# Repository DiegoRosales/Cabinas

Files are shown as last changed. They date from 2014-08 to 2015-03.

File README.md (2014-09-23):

Proyecto Cabinas
=======
---

**Última revisión del PCB del control:** 09/09/2014.

**Última revisión del PCB de la botonera:** 29/07/2014.

**Última revisión del código del control:** 23/09/2014.

**Última revisión del código de la botonera:** 1/09/2014

# Esquemático del PCB de control

# Esquemático de la botonera

# Tabla de cableado

# BOM
[Bill of materials](https://github.com/DiegoRosales/Cabinas/blob/master/PCB/Cabinas/BOM/BOM.xlsx)

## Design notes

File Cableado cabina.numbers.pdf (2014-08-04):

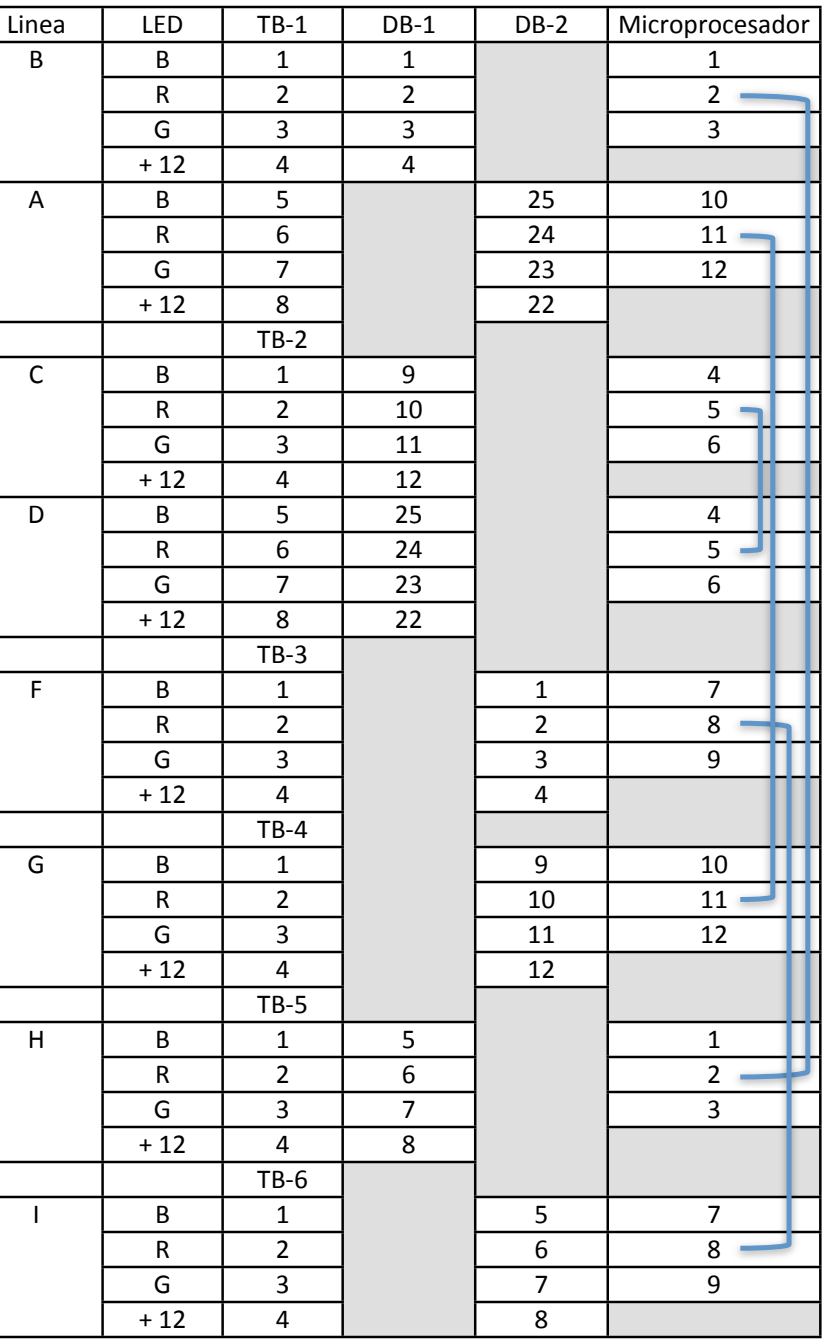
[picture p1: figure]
Linea; LED; Microprocesador

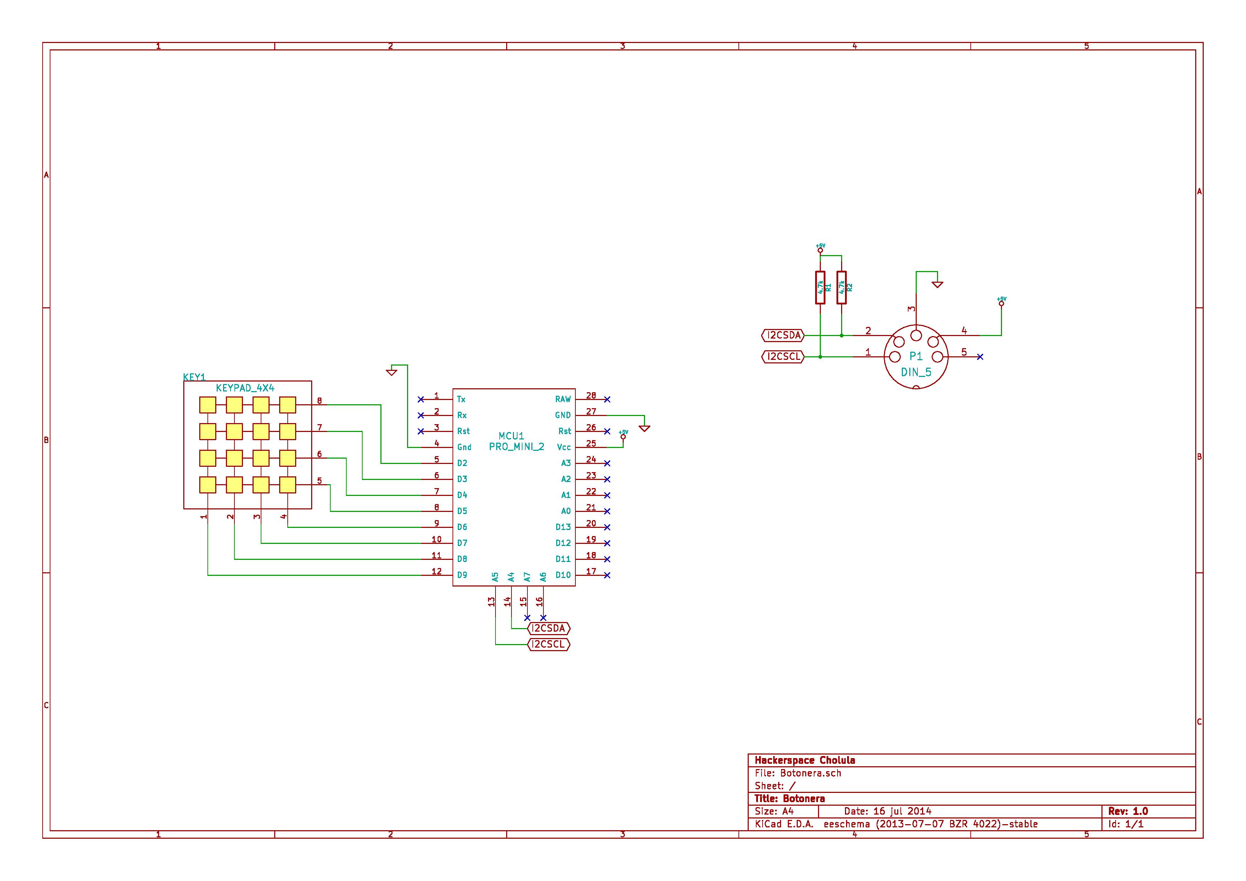
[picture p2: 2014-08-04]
PCB/Botonera/Schematic.jpg

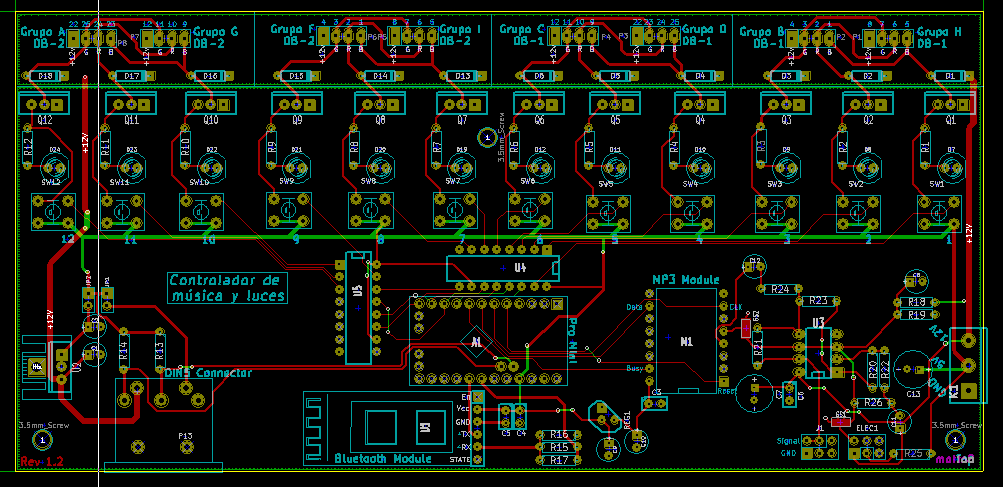
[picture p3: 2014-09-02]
Captura.PNG

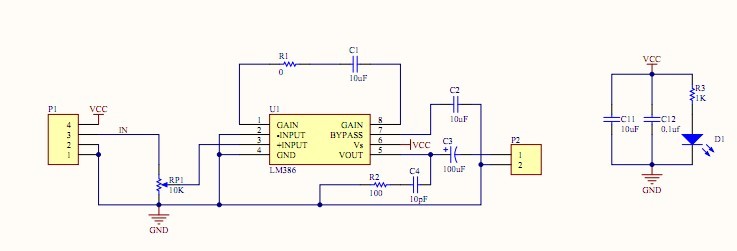
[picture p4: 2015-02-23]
PCB/Cabinas/Esquematico/lm386 mini circuit.jpg

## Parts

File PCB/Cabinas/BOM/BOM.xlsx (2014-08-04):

Reference | Value | Type
A1 | - | Arduino Pro Mini 5V
C1 | 0.33uF | Ceramic Capacitor
C9, C10, C11, C12 | 1uF | Electrolytic Capacitor
C7, C13 | 470uF | Electrolytic Capacitor
C2, C3, C4, C5, C6 | 0.1uF | Ceramic Capacitor
C8 | 47uF | Electrolytic Capacitor
D7, D8, D9, D10, D11, D12, D19, D20, D21, D22, D23, D24 | LED | LED
D1, D2, D3, D4, D5, D6D13, D14, D15, D16, D17, D18 | 1N4001 | Diode
ELEC1 | - | Electret Microphone
GS1 | - | Solder jumper
GS2 | - | Solder jumper
J1 | JACK_ST_3SW | Jack
JP1, JP2 | - | Pin header 2x
K1 | - | Pin header 3x
M1 | WTV020-SD | MP3 Module
P1, P2, P3, P4, P5, P6, P7, P8 | - | LED Strip output
P13 | - | DIN 5 Connector
Q1, Q2, Q3, Q4, Q5, Q6, Q7, Q8, Q9, Q10, Q11, Q12 |  | Mosfet transistor
R1, R2, R3, R4, R5, R6, R7, R8, R9, R10, R11, R12, R15, R16, R17 | 1k | Resistor
R13, R14 | 4.7k | Resistor
R18, R19, R21, R22, R23, R24, R26 | 10k | Resistor
R20 | 270k | Resistor
R25 | 2.2k | Resistor
REG1 | NPC1700 | 3.3V Regulator
SW1, SW2, SW3, SW4, SW5, SW6, SW7, SW8, SW9, SW10, SW11, SW12 | - | Tactile Switch
U1 | - | Bluetooth module
U2 | 7805 | 5V Regulator
U3 | TL072 | Operational Amplifier
U4, U5 | 74HC595 | Shift Register

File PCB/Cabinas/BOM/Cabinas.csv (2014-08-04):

ref | value
A1 | PROMINI
C1 | 0.33uF
C2 | 0.1uF
C3 | 0.1uF
C4 | 0.1uF
C5 | 0.1uF
C6 | 0.1uF
C7 | 470uF
C8 | 47uF
C9 | 1uF
C10 | 1uF
C11 | 1uF
C12 | 1uF
C13 | 470uF
D1 | DIODE
D2 | DIODE
D3 | DIODE
D4 | DIODE
D5 | DIODE
D6 | DIODE
D7 | LED
D8 | LED
D9 | LED
D10 | LED
D11 | LED
D12 | LED
D13 | DIODE
D14 | DIODE
D15 | DIODE
D16 | DIODE
D17 | DIODE
D18 | DIODE
D19 | LED
D20 | LED
D21 | LED
D22 | LED
D23 | LED
D24 | LED
ELEC1 | ELECTRET_MIC_SUP
GS1 | GS3
GS2 | GS3
J1 | JACK_ST_3SW
JP1 | JUMPER
JP2 | JUMPER
K1 | CONN_3
M1 | WTV020-SD
P1 | CONN_4
P2 | CONN_4
P3 | CONN_4
P4 | CONN_4
P5 | CONN_4
P6 | CONN_4
P7 | CONN_4
P8 | CONN_4
P13 | DIN_5
Q1 | MOSFET_N
Q2 | MOSFET_N
Q3 | MOSFET_N
Q4 | MOSFET_N
Q5 | MOSFET_N
Q6 | MOSFET_N
Q7 | MOSFET_N
Q8 | MOSFET_N
Q9 | MOSFET_N
Q10 | MOSFET_N
Q11 | MOSFET_N
Q12 | MOSFET_N
R1 | 1k
R2 | 1k
R3 | 1k
R4 | 1k
R5 | 1k
R6 | 1k
R7 | 1k
R8 | 1k
R9 | 1k
R10 | 1k
R11 | 1k
R12 | 1k
R13 | 4.7k
R14 | 4.7k
R15 | 1k
R16 | 1k
R17 | 1k
R18 | 10k
R19 | 10k
R20 | 270k
R21 | 10k
R22 | 10k
R23 | 10k
R24 | 10k
R25 | 2.2k
R26 | 10k
REG1 | NPC1700
SW1 | PUSHBUTTON
SW2 | PUSHBUTTON
SW3 | PUSHBUTTON
SW4 | PUSHBUTTON
SW5 | PUSHBUTTON
SW6 | PUSHBUTTON
SW7 | PUSHBUTTON
SW8 | PUSHBUTTON
SW9 | PUSHBUTTON
SW10 | PUSHBUTTON
SW11 | PUSHBUTTON
SW12 | PUSHBUTTON
U1 | BTM_2
U2 | 7805
U3 | TL072
U4 | 74HC595
U5 | 74HC595

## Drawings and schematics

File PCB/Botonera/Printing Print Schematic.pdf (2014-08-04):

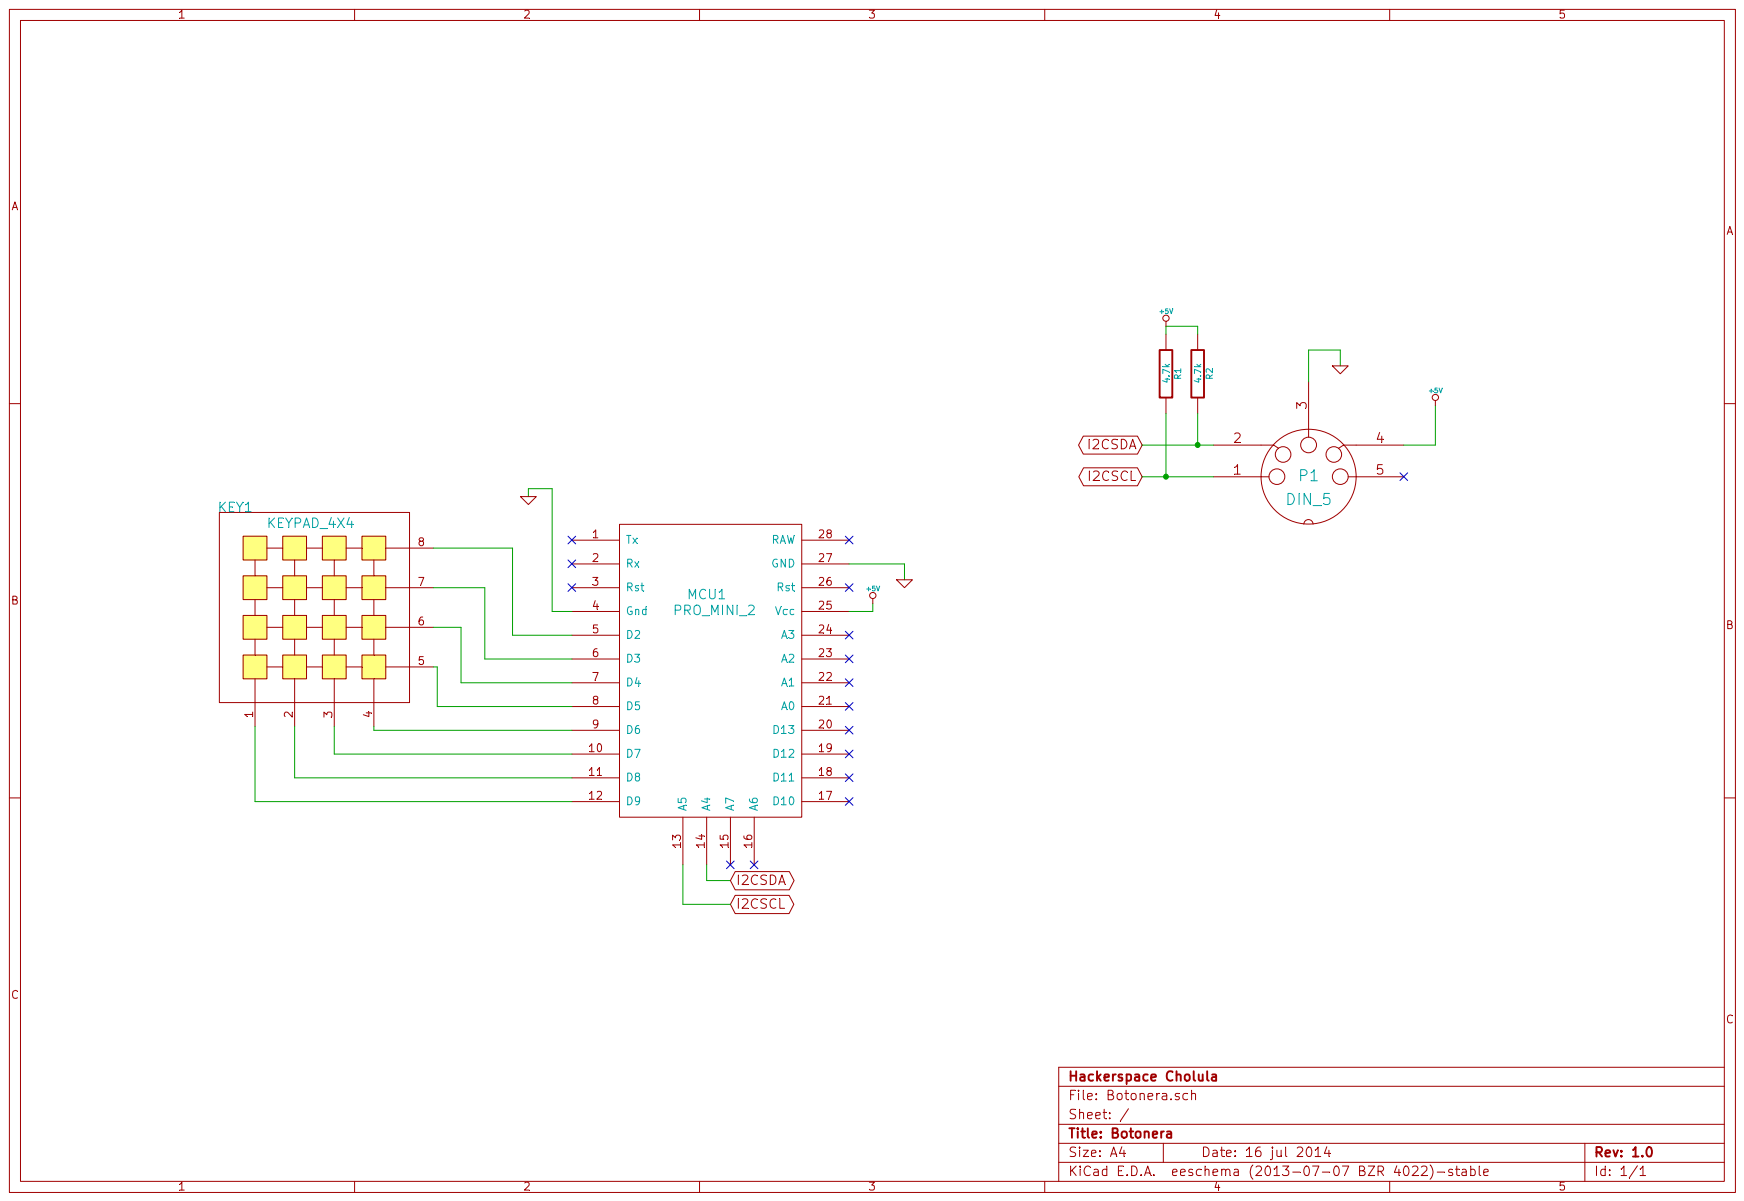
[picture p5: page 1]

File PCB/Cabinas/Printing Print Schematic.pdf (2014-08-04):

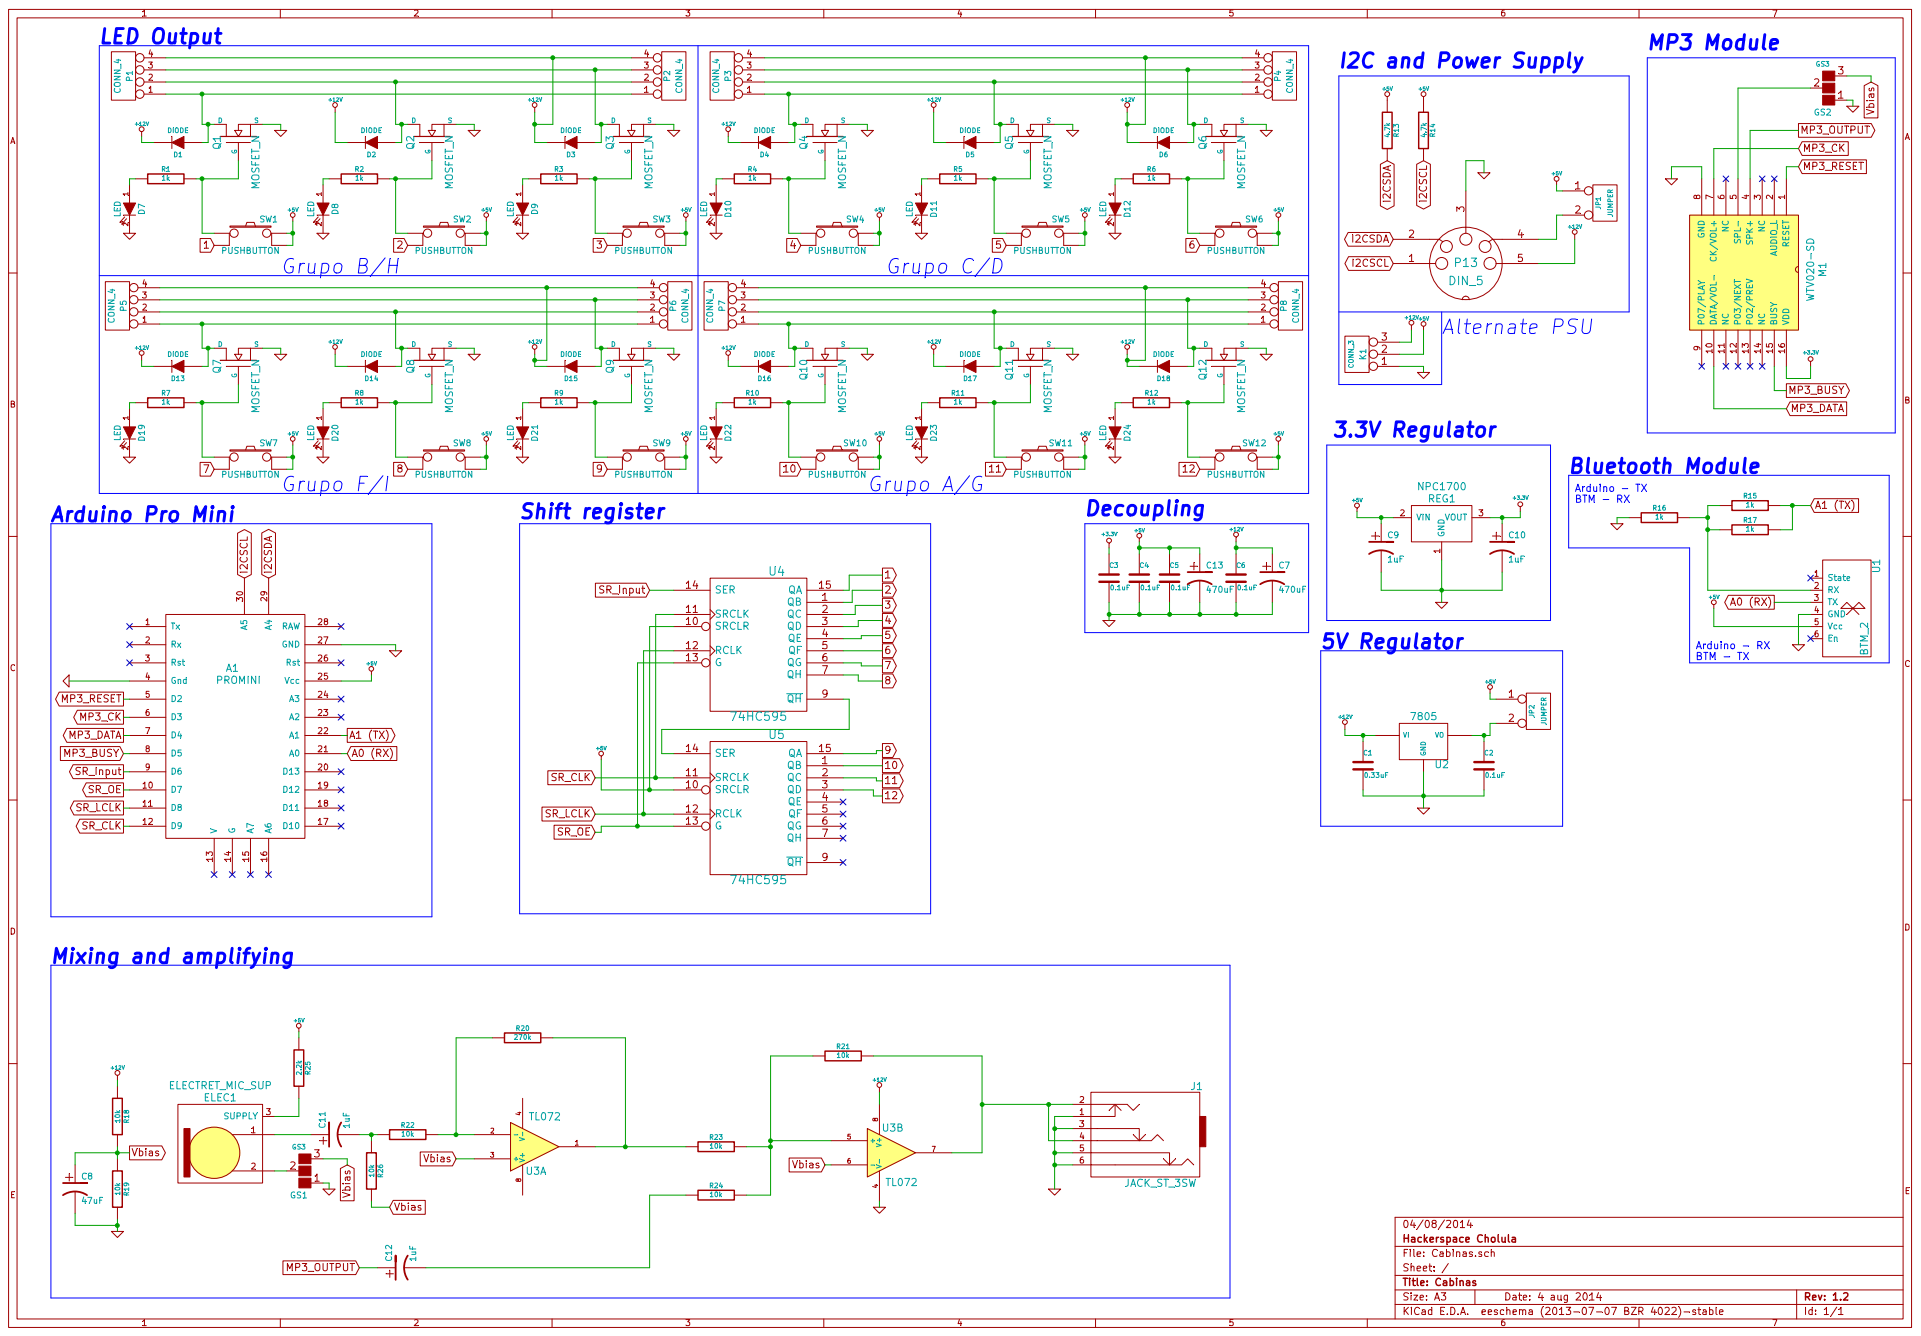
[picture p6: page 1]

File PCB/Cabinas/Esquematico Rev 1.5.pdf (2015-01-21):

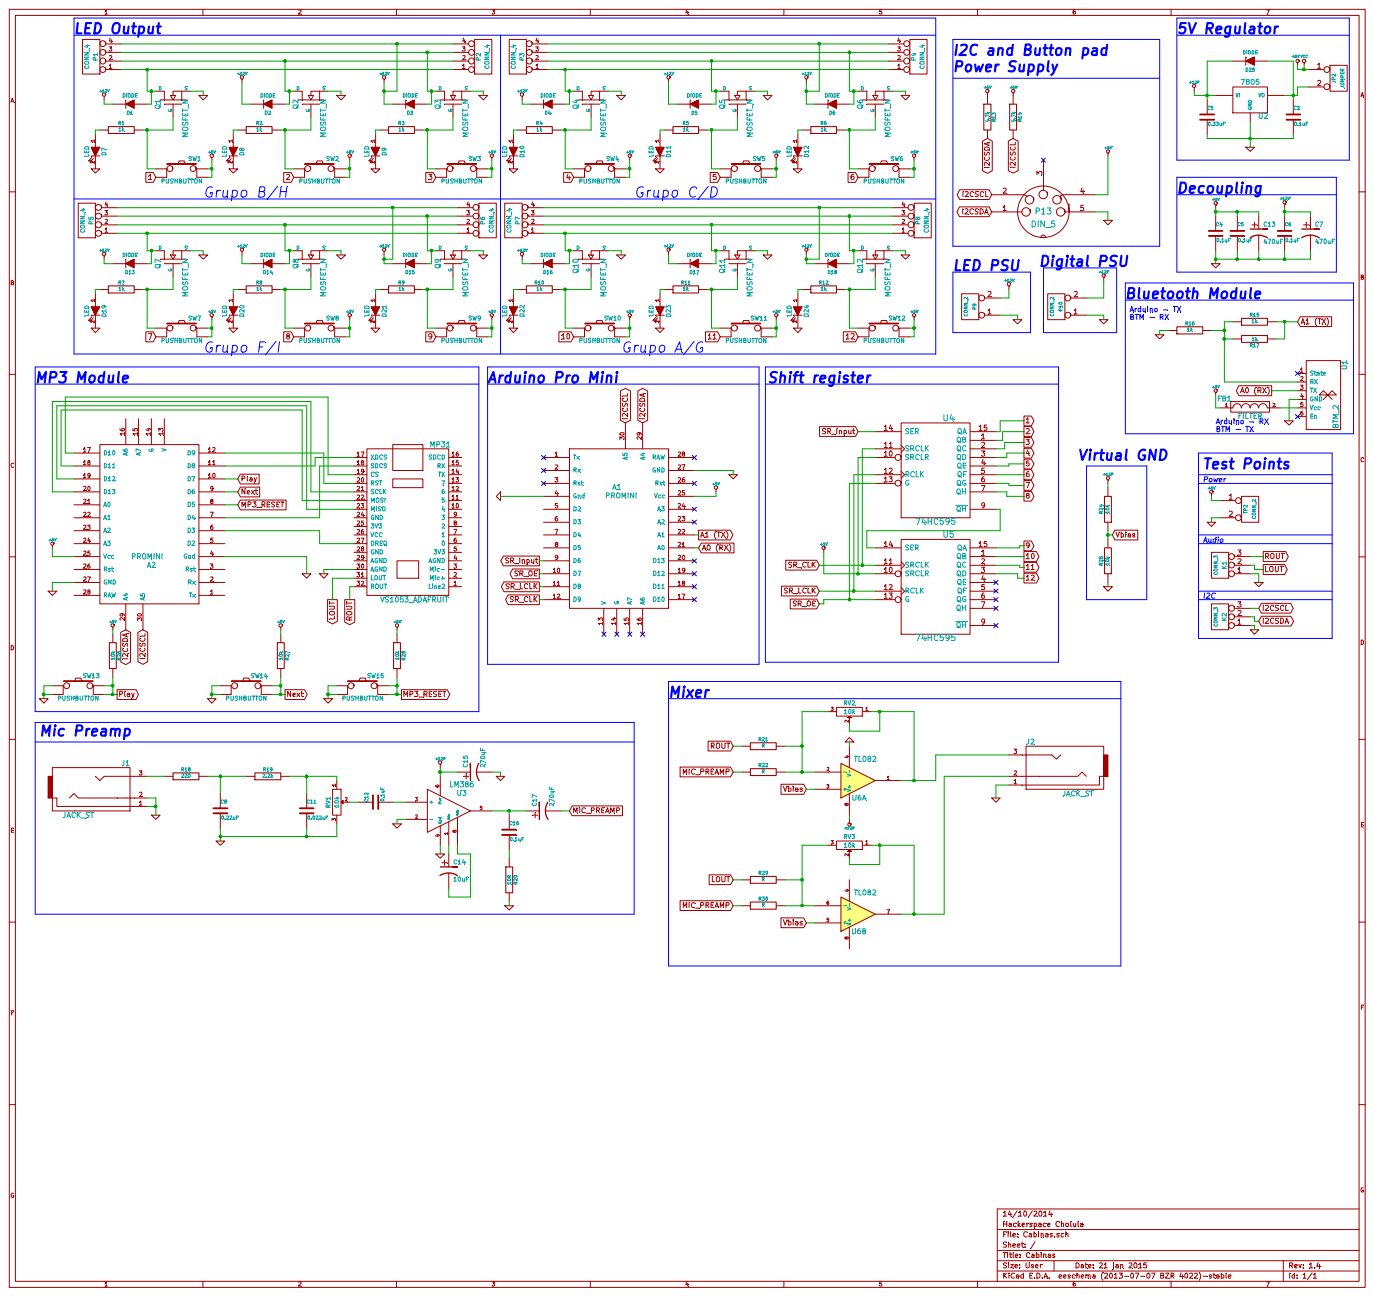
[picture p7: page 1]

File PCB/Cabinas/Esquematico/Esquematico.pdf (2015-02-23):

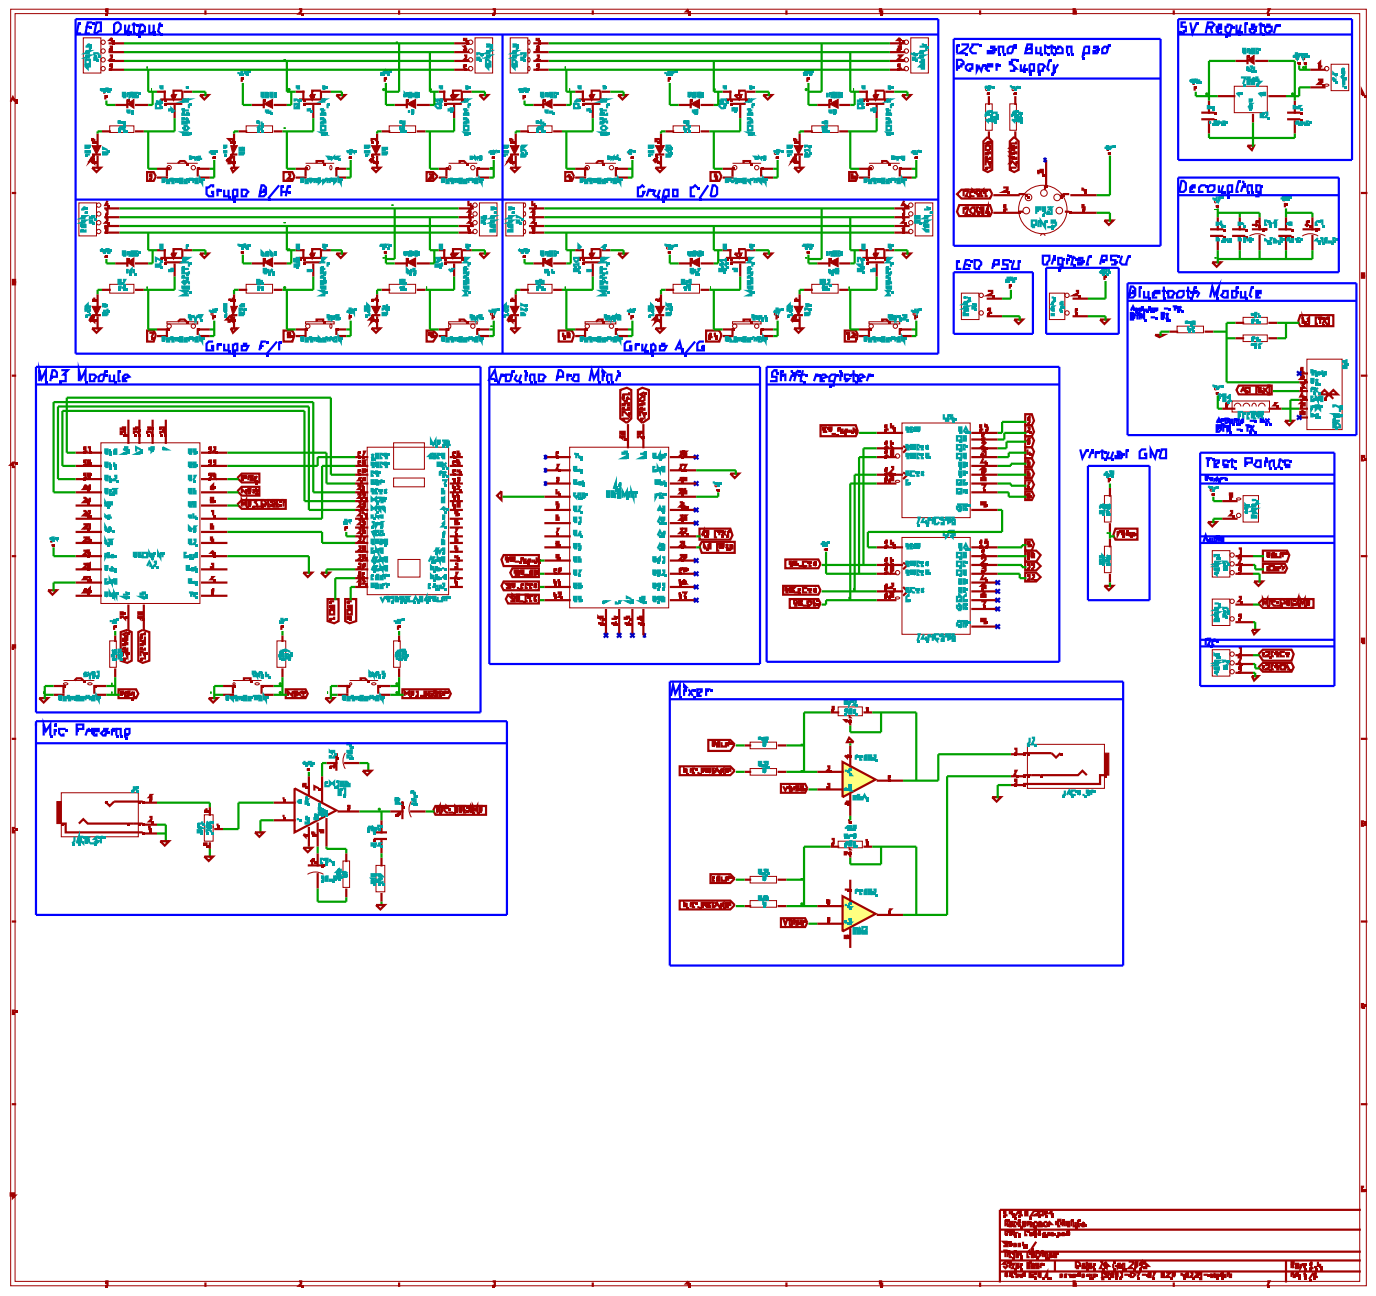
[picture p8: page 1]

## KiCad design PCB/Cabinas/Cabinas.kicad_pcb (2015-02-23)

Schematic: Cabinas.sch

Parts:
A1, A2: PROMINI
C1: 0.33uF
C2, C4, C5, C6: 0.1uF
C3, C8, C14: 10uF
C7, C13: 470uF
C12: 10pF
D1, D2, D3, D4, D5, D6, D13, D14, D15, D16, D17, D18, D25: DIODE
D7, D8, D9, D10, D11, D12, D19, D20, D21, D22, D23, D24: LED
FB1: FILTER
J1, J2: JACK_ST
JP2: JUMPER
K1, K2: CONN_3
MP31: VS1053_ADAFRUIT
P1, P2, P3, P4, P5, P6, P7, P8: CONN_4
P9, P10, P11: CONN_2
P13: DIN_5
Q1, Q2, Q3, Q4, Q5, Q6, Q7, Q8, Q9, Q10, Q11, Q12: MOSFET_N
R1, R2, R3, R4, R5, R6, R7, R8, R9, R10, R11, R12, R15, R16, R17: 1k
R13, R14: 4.7k
R18: 0R
R19: 100
R21, R22, R29, R30: R
R24, R25, R26, R27, R28: 10k
RV1, RV2, RV3: 10k
SW1, SW2, SW3, SW4, SW5, SW6, SW7, SW8, SW9, SW10, SW11, SW12, SW13, SW14, SW15: PUSHBUTTON
TP2: CONN_2
U1: BTM_2
U2: 7805
U3: LM386
U4, U5: 74HC595
U6: TL082

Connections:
1: SW1.2, U4.15 (QA)
2: SW2.2, U4.1 (QB)
3: SW3.2, U4.2 (QC)
4: SW4.2, U4.3 (QD)
5: SW5.2, U4.4 (QE)
6: SW6.2, U4.5 (QF)
7: SW7.2, U4.6 (QG)
8: SW8.2, U4.7 (QH)
9: SW9.2, U5.15 (QA)
10: SW10.2, U5.1 (QB)
11: SW11.2, U5.2 (QC)
12: SW12.2, U5.3 (QD)
+5V: A1.25 (Vcc), A2.25 (Vcc), C4.1, C5.1, C13.1, FB1.1, JP2.1, MP31.26 (VCC), P13.4, R13.1, R14.1, R26.1, R27.1, R28.1, SW1.3, SW1.4, SW2.3, SW2.4, SW3.3, SW3.4, SW4.3, SW4.4, SW5.3, SW5.4, SW6.3, SW6.4, SW7.3, SW7.4, SW8.3, SW8.4, SW9.3, SW9.4, SW10.3, SW10.4, SW11.3, SW11.4, SW12.3, SW12.4, TP2.1, U4.10 (SRCLR), U4.16 (VCC), U5.10 (SRCLR), U5.16 (VCC); also elsewhere on the board
+12P: C1.1, D25.2 (K), P10.2 (PM), R24.2, U2.VI, U2.Vi, U6.8 (V+); also elsewhere on the board
+12V: C6.1, C7.1, D1.2 (K), D2.2 (K), D3.2 (K), D4.2 (K), D5.2 (K), D6.2 (K), D13.2 (K), D14.2 (K), D15.2 (K), D16.2 (K), D17.2 (K), D18.2 (K), P1.4, P2.4, P3.4, P4.4, P5.4, P6.4, P7.4, P8.4, P9.2 (PM), U3.6 (Pwr)
A0 (RX): A1.21 (A0), U1.3 (TX)
A1 (TX): A1.22 (A1), R15.2, R17.1
GND: A1.4 (Gnd), A1.27 (GND), A2.4 (Gnd), A2.27 (GND), C1.2, C2.2, C3.2, C4.2, C5.2, C6.2, C7.2, C13.2, D7.2 (K), D8.2 (K), D9.2 (K), D10.2 (K), D11.2 (K), D12.2 (K), D19.2 (K), D20.2 (K), D21.2 (K), D22.2 (K), D23.2 (K), D24.2 (K), J1.1, J1.2, J2.1, K1.1, K2.1, MP31.30 (AGND), P9.1, P10.1, P11.1, P13.5, Q1.S, Q2.S, Q3.S, Q4.S, Q5.S, Q6.S, Q7.S, Q8.S, Q9.S, Q10.S, Q11.S, Q12.S, R16.1, R19.1, R25.1, RV1.3, SW13.1, SW13.2, SW14.1, SW14.2, SW15.1, SW15.2, TP2.2 (PM), U1.4 (GND), U2.GND, U3.2 (-), U3.4 (Gnd), U4.8 (GND), U5.8 (GND), U6.4 (V-); also elsewhere on the board
I2CSCL: A1.30 (A5), A2.30 (A5), K2.3, P13.2, R14.2
I2CSDA: A1.29 (A4), A2.29 (A4), K2.2 (PM), P13.1, R13.2
LOUT: K1.2 (PM), MP31.31 (LOUT), R29.1
MIC_PREAMP: C8.2, P11.2 (PM), R22.1, R30.1
MP3_RESET: A2.8 (D5), R28.2, SW15.3, SW15.4
unnamed: D16.1 (A), P7.1, P8.1, Q10.D
unnamed: Q10.G, R10.2, SW10.1
unnamed: D21.1 (A), R9.1
unnamed: Q9.G, R9.2, SW9.1
unnamed: D17.1 (A), P7.2, P8.2, Q11.D
unnamed: D23.1 (A), R11.1
unnamed: Q11.G, R11.2, SW11.1
unnamed: D22.1 (A), R10.1
unnamed: D14.1 (A), P5.2, P6.2, Q8.D
unnamed: D19.1 (A), R7.1
unnamed: Q7.G, R7.2, SW7.1
unnamed: D15.1 (A), P5.3, P6.3, Q9.D
unnamed: D20.1 (A), R8.1
unnamed: Q8.G, R8.2, SW8.1
unnamed: C2.1, D25.1 (A), JP2.2 (PM), U2.VO, U2.Vo
unnamed: U4.9 (~QH), U5.14 (SER)
unnamed: D24.1 (A), R12.1
unnamed: Q12.G, R12.2, SW12.1
unnamed: D18.1 (A), P7.3, P8.3, Q12.D
unnamed: R15.1, R16.2, R17.2, U1.2 (RX)
unnamed: D7.1 (A), R1.1
unnamed: Q1.G, R1.2, SW1.1
unnamed: D1.1 (A), P1.1, P2.1, Q1.D
unnamed: D8.1 (A), R2.1
unnamed: Q2.G, R2.2, SW2.1
unnamed: D2.1 (A), P1.2, P2.2, Q2.D
unnamed: R29.2, R30.2, RV3.3, U6.6 (-)
unnamed: R21.2, R22.2, RV2.3, U6.2 (-)
unnamed: D11.1 (A), R5.1
unnamed: D6.1 (A), P3.3, P4.3, Q6.D
unnamed: Q5.G, R5.2, SW5.1
unnamed: D12.1 (A), R6.1
unnamed: D13.1 (A), P5.1, P6.1, Q7.D
unnamed: Q6.G, R6.2, SW6.1
unnamed: D9.1 (A), R3.1
unnamed: Q3.G, R3.2, SW3.1
unnamed: D4.1 (A), P3.1, P4.1, Q4.D
unnamed: D3.1 (A), P1.3, P2.3, Q3.D
unnamed: Q4.G, R4.2, SW4.1
unnamed: D10.1 (A), R4.1
unnamed: A2.17 (D10), MP31.19 (CS)
unnamed: A2.12 (D9), MP31.20 (RST)
unnamed: A2.11 (D8), MP31.17 (XDCS)
unnamed: A2.7 (D4), MP31.18 (SDCS)
unnamed: A2.6 (D3), MP31.27 (DREQ)
unnamed: J2.3, RV2.1, RV2.2, U6.1
unnamed: A2.19 (D12), MP31.23 (MISO)
unnamed: A2.18 (D11), MP31.22 (MOSI)
unnamed: A2.20 (D13), MP31.21 (SCLK)
unnamed: R18.2, U3.8 (Gain)
unnamed: C14.2, R18.1
unnamed: C8.1, C12.2, U3.5
unnamed: C12.1, R19.2
unnamed: C3.1, U3.7 (Bypass)
unnamed: J2.2, RV3.1, RV3.2, U6.7
unnamed: RV1.2, U3.3 (+)
unnamed: J1.3, RV1.1
unnamed: D5.1 (A), P3.2, P4.2, Q5.D
unnamed: C14.1, U3.1 (Gain)
unnamed: FB1.2, U1.5 (Vcc)
Next: A2.9 (D6), R27.2, SW14.3, SW14.4
Play: A2.10 (D7), R26.2, SW13.3, SW13.4
ROUT: K1.3, MP31.32 (ROUT), R21.1
SR_CLK: A1.12 (D9), U4.11 (SRCLK), U5.11 (SRCLK)
SR_Input: A1.9 (D6), U4.14 (SER)
SR_LCLK: A1.11 (D8), U4.12 (RCLK), U5.12 (RCLK)
SR_OE: A1.10 (D7), U4.13 (G), U5.13 (G)
Vbias: R24.1, R25.2, U6.3 (+), U6.5 (+)

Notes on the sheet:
Arduino - TX BTM - RX
Arduino - RX BTM - TX
Bluetooth Module
MP3 Module
I2C and Button pad Power Supply
5V Regulator
Arduino Pro Mini
Decoupling
LED Output
LED PSU
Shift register
Grupo A/G
Grupo B/H
Grupo C/D
Grupo F/I
Digital PSU
Test Points
Mixer
Mic Preamp
Virtual GND
Power
Audio
I2C

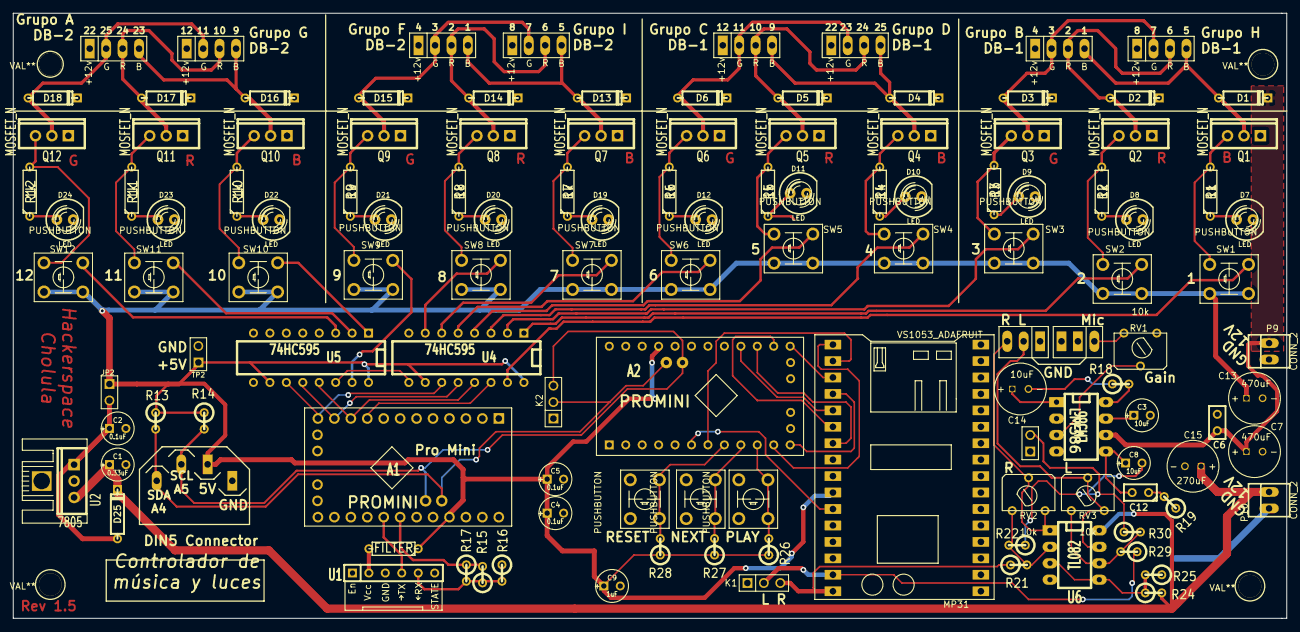
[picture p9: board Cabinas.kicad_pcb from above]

Board: 2 copper layers, 196.7 x 93.5 mm, 128 parts (0 on the bottom side), 91 nets.

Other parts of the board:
3.5mm_Screw, 3.5mm_Screw#2, 3.5mm_Screw#3, 3.5mm_Screw#4: VAL**; 3.5mm_Screw
C9: 1uF; C1V5
C15: 270uF; CAP_8_3.5

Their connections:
+5V: C9.1; also elsewhere on the board
+12P: C15.1; also elsewhere on the board
GND: C9.2, C15.2; also elsewhere on the board

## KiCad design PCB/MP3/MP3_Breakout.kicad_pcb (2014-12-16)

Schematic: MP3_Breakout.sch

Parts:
K1: CONN_3
MCU1: PRO_MINI_2
MP31: VS1053_ADAFRUIT
P1, P2: CONN_2

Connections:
+5V: MCU1.25, MP31.26 (VCC), P1.1
/A4_SDA: MCU1.14, P2.1
/A5_SCL: MCU1.13, P2.2 (PM)
GND: K1.3, MCU1.27, MP31.24 (GND), P1.2 (PM)
unnamed: K1.1, MP31.31 (LOUT)
unnamed: MCU1.20, MP31.21 (SCLK)
unnamed: MCU1.6, MP31.27 (DREQ)
unnamed: K1.2 (PM), MP31.32 (ROUT)
unnamed: MCU1.12, MP31.20 (RST)
unnamed: MCU1.17, MP31.19 (CS)
unnamed: MCU1.19, MP31.23 (MISO)
unnamed: MCU1.7, MP31.18 (SDCS)
unnamed: MCU1.11, MP31.17 (XDCS)
unnamed: MCU1.18, MP31.22 (MOSI)

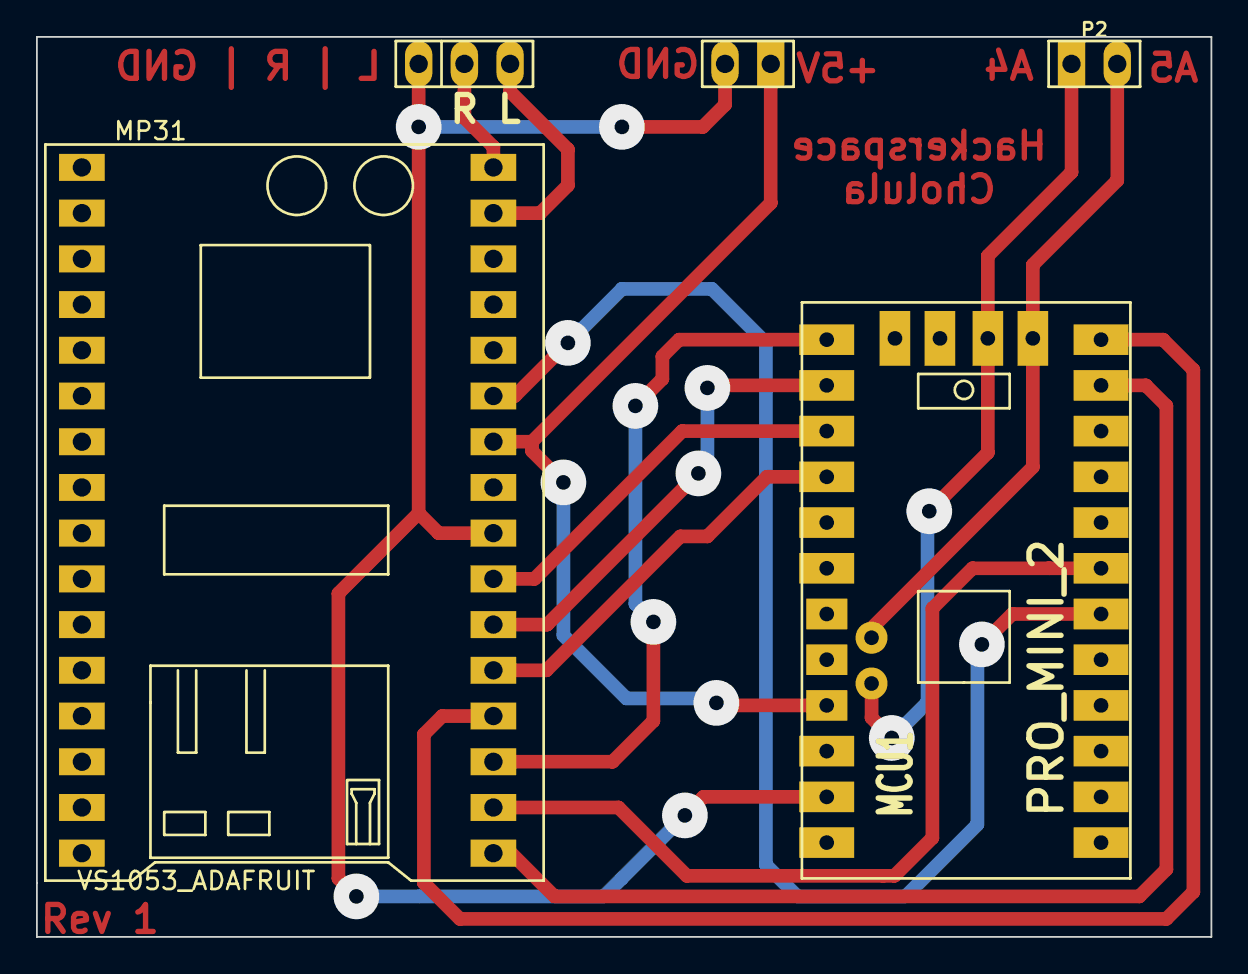
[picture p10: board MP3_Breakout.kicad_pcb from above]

Board: 2 copper layers, 65.2 x 50.0 mm, 5 parts (0 on the bottom side), 14 nets.

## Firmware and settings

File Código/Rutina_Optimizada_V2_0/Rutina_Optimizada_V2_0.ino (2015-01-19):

#include <SoftwareSerial.h>
#include <Wtv020sd16p.h> //Librería del MP3
#include <Wire.h>
#include <ShiftReg.h>
#include "Const_seq.h"
#include "Seq.h"
#include "TimerOne.h"

#define TIEMPOMAXIMO 25

#define ID_BOTONERA 4

extern int const seq1[20];
extern int const seq2[20];
extern int const seq3[20];

// ---- MP3 Pins ---
int resetPin = 2;   // The pin number of the reset pin.
int clockPin = 3;   // The pin number of the clock pin.
int dataPin = 4;    // The pin number of the data pin.
int busyPin = 5;    // The pin number of the busy pin

// ---- Global variables ---
int n;               // Variable auxiliar para determinar pin de salida del Arduino
int rutina;          // Número de rutina
int secuencia[20];   // Matriz de transferencia/copia de secuencias
int leerparo;        // Variable auxiliar para disparar paro
int paro;            // Variable que identifica si se precionó la tecla/botón paro
bool ROJO1 = false;
bool VERDE1 = false;
bool AZUL1 = false;
int ROJO = 0;
int AZUL = 0;
int VERDE = 0;
int rutina_temp = 0;
int rutina_temp2 = 3;
int tiempoMaximo = 0;

// --- Modules ---
ShiftReg shiftReg;
Wtv020sd16p wtv020sd16p(resetPin, clockPin, dataPin, busyPin); //Se declara el modulo MP3
SoftwareSerial mySerial(14, 15); // RX, TX
bool I2C = false;


void setup() {
  /*--------------------------------------------*/
  /*  Bluetooth Module & Serial Initialization  */
  mySerial.begin(9600);
  mySerial.println("Iniciando...");
  mySerial.println("Hackerspace Cholula");
  mySerial.println("Firmware V2.2");
  mySerial.println("19/01/2015");
  Serial.begin(9600);

  /*----------------------*/
  /*  I2C Initialization  */
  Wire.begin(4);                // join i2c bus with address #4
  Wire.onReceive(receiveEvent); // register event

  /*----------------------------------*/
  /*  Shift Registers Initialization  */
  for (int i = 6; i <= 9; i++)
    pinMode(i, OUTPUT);
  /* Welcome sequence */
  for (int i = 0; i < 12; i++) // All off
    shiftReg.digitalWriteMS(1, i, LOW);
  for (int i = 0; i < 12; i++) { // All on
    shiftReg.digitalWriteMS(1, i, HIGH);
    delay(50);
  }
  for (int i = 0; i < 12; i++) { // All off
    shiftReg.digitalWriteMS(1, i, LOW);
    delay(50);
  }
  delay(1000);
  /*-----------------------------*/
  /*  MP3 Module Initialization  */
  pinMode(dataPin, OUTPUT);
  pinMode(clockPin, OUTPUT);
  wtv020sd16p.reset(); // MP3 Reset
  //while (digitalRead(busyPin) == HIGH) {
  //  Serial.println("Cargando MP3...");
  //  mySerial.println("Cargando MP3...");
  //  delay(100);
  //}
  wtv020sd16p.unmute();
  //wtv020sd16p.playVoice(1); // Test
  
  Timer1.initialize(200000);         // initialize timer1, and set a 1/2 second period
  Timer1.attachInterrupt(LEDTest);  // attaches callback() as a timer overflow interrupt
  //Timer1.stop();
  // Controller is ready
  mySerial.println("Listo!!");
  mySerial.println("------------------------------");
  mySerial.println("Favor de ingresar la rutina...");
  
  mySerial.println();

  Serial.println("Listo!!");
  Serial.println("Favor de ingresar la rutina...");
  Serial.println("------------------------------");
  Serial.println();
}

void LEDTest() {
 
  if(VERDE == 2){
    //mySerial.println("Verde parpadeando");
    for (int i = 2; i < 12; i = i + 3) {
      if (VERDE1 == 0)
        shiftReg.digitalWriteMS(1, i, HIGH);
      else
        shiftReg.digitalWriteMS(1, i, LOW);
    }
    VERDE1 = !VERDE1;  
  }
  
  if(ROJO == 2){
    //mySerial.println("Rojo parpadeando");
    for (int i = 1; i < 12; i = i + 3) {
      if (ROJO1 == 0)
        shiftReg.digitalWriteMS(1, i, HIGH);
      else
        shiftReg.digitalWriteMS(1, i, LOW);
    }
    ROJO1 = !ROJO1;  
  }
  
  if(AZUL == 2){
    for (int i = 0; i < 12; i = i + 3) {
      if (AZUL1 == 0)
        shiftReg.digitalWriteMS(1, i, HIGH);
      else
        shiftReg.digitalWriteMS(1, i, LOW);
    }
    AZUL1 = !AZUL1;
  }
  
  if(AZUL != 0 && VERDE != 0  && ROJO != 0){
    tiempoMaximo++;
    if(tiempoMaximo%5 == 0){
      mySerial.print("Apagando en ");
      mySerial.print(TIEMPOMAXIMO/5 - tiempoMaximo/5);
      mySerial.println(" segundos");
    }
  }else
    tiempoMaximo = 0;
  
  if(tiempoMaximo > TIEMPOMAXIMO){
    tiempoMaximo = 0;
    mySerial.println("Apagando luces...");
    for(int i=0; i<12; i++)
      shiftReg.digitalWriteMS(1, i, LOW);
    ROJO1 = false;
    VERDE1 = false;
    AZUL1 = false;
    ROJO = 0;
    VERDE = 0;
    AZUL = 0;
    mySerial.println("Luces apagadas");
    mySerial.println("------------------------------");
  }
}

//------------------------------
//------------------------------
// Rutina de interrupción de I2C
void receiveEvent(int howMany)
{
  Serial.println("Wire!!");
  char x = Wire.read();
  if (x == 71){
    //apagar();
    leerparo = 'x';
    Serial.println("I2C Paro");
  }else
    rutina = x;
  Serial.println("Botonera");
  Serial.println(x);
  I2C = true;
}

void loop() {

  if (mySerial.available() > 0 || Serial.available() || I2C) {
    leerparo = 0;
    paro = 0;
    // Decide de dónde vino la información
    if (mySerial.available()) // Modulo bluetooth
      rutina = mySerial.read();
    else if (I2C) // Botonera
      mySerial.println("I2C");
    else // Ventana de comando
      rutina = Serial.read();
    I2C = false;
    mySerial.flush();

    Serial.flush();
    Serial.print("El numero de codigo es: "); // Prueba
    Serial.println(rutina-49, BIN); // Prueba
    Serial.println();

    switch (rutina) {

        // Rutina 1, 2 o 3
      case '1':
      case '2':
      case '3':
      case '4':
      case '5':
      case '6':
        ejecutarRutina(rutina);
        break;

        /*---- COLORES SÓLIDOS ---*/

        // Azul
      case '7':
          if (AZUL == 0)
            mySerial.println("Color azul encendido");
          else if (AZUL == 1)
            mySerial.println("Color azul parpadeando");
          else
            mySerial.println("Color azul apagado");
            
          // Enciende los LEDs
          for (int i = 0; i < 12; i = i + 3) {
            if (AZUL == 0)
              shiftReg.digitalWriteMS(1, i, HIGH);
            else if (AZUL == 2)
              shiftReg.digitalWriteMS(1, i, LOW);
          }
          if(AZUL == 2)
            AZUL = 0;
          else
            AZUL++;
        //mySerial.println(AZUL);
        paro = 0;
        mySerial.println("----------------------------");
        mySerial.println();
        break;

        // Rojo
      case '8':
          if (ROJO == 0)
            mySerial.println("Color rojo encendido");
          else if (ROJO == 1)
            mySerial.println("Color rojo parpadeando");
          else if (ROJO == 2)
            mySerial.println("Color rojo apagado");
            
          // Enciende los LEDs
          for (int i = 1; i < 12; i = i + 3) {
            if (ROJO == 0){
              shiftReg.digitalWriteMS(1, i, HIGH);
              ROJO1 = true;
            }
            else if (ROJO == 2){
              shiftReg.digitalWriteMS(1, i, LOW);
          }
        }
        if(ROJO == 2)
          ROJO = 0;
        else
          ROJO++;
        paro = 0;
        mySerial.println("----------------------------");
        mySerial.println();
        break;

        // Verde
      case '9':
          if (VERDE == 0)
            mySerial.println("Color verde encendido");
          else if (VERDE == 1)
            mySerial.println("Color verde parpadeando");
          else if (VERDE == 2)
            mySerial.println("Color verde apagado");

          // Enciende los LEDs
          for (int i = 2; i < 12; i = i + 3) {
            if (VERDE == 0){
              shiftReg.digitalWriteMS(1, i, HIGH);
              //VERDE1 = true;
            }
            else if (VERDE == 2) {
              shiftReg.digitalWriteMS(1, i, LOW);
            }
          }
          
          if(VERDE == 2)
            VERDE = 0;
          else
            VERDE++;
        paro = 0;
        //mySerial.println(VERDE);
        mySerial.println("----------------------------");
        mySerial.println();
        break;

      // Va ciclando las secuencias
      case '*':
        //rutina_temp = 1;
        //ejecutarRutina(rutina_temp+48);
        if(rutina_temp > 2){
          apagar();
          rutina_temp = 0;
        }else{
          mySerial.print("Iniciando cancion ");
          mySerial.println(rutina_temp + 1);
          //wtv020sd16p.asyncPlayVoice(rutina_temp);
          changeTrack(rutina_temp+1);
          rutina_temp++;
        }
        break;
        
      case '#':
        //rutina_temp2 = 3;

        if(rutina_temp2 > 5){
          apagar();
          rutina_temp2 = 3;
        }else{
          mySerial.print("Iniciando cancion ");
          mySerial.println(rutina_temp2 + 1);
          //wtv020sd16p.asyncPlayVoice(rutina_temp2);
          changeTrack(rutina_temp2+1);
          rutina_temp2++;
        }
        break;
        
        // Se apaga todo
      case 'x':
        apagar();
        break;

        I2C = false;
        mySerial.println("Fin de rutina");
    }
  }
}

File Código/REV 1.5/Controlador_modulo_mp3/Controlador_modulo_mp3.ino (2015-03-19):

// include SPI, MP3 and SD libraries
#include <SPI.h>
#include <Adafruit_VS1053.h>
#include <SD.h>
#include <Wire.h>

//----- MP3 Module Pins -----
#define BREAKOUT_RESET  9      // VS1053 reset pin (output)
#define BREAKOUT_CS     10     // VS1053 chip select pin (output)
#define BREAKOUT_DCS    8      // VS1053 Data/command select pin (output)
// These are common pins between breakout and shield
#define CARDCS 4     // Card chip select pin
// DREQ should be an Int pin, see http://arduino.cc/en/Reference/attachInterrupt
#define DREQ 3       // VS1053 Data request, ideally an Interrupt pin


// --- Test push buttons ---
#define RESET_PB 5
#define NEXT_PB 6
#define PLAY_PB 7

uint8_t currentTrackTest = 0;
bool playing = false;

Adafruit_VS1053_FilePlayer musicPlayer =
  Adafruit_VS1053_FilePlayer(BREAKOUT_RESET, BREAKOUT_CS, BREAKOUT_DCS, DREQ, CARDCS);

char x = 0;

void setup() {
  Serial.begin(9600);
  Serial.println("Initializing MP3 module");
  if (! musicPlayer.begin()) { // initialise the music player
    Serial.println(F("Couldn't find VS1053, do you have the right pins defined?"));
    while (1);
  }
  Serial.println(F("VS1053 found"));

  if (!SD.begin(CARDCS)) Serial.println("Error initializing SD card");
  else Serial.println("SD card initialized correctly!");  // initialise the SD card

  // Set volume for left, right channels. lower numbers == louder volume!
  musicPlayer.setVolume(5, 5);

  // Timer interrupts are not suggested, better to use DREQ interrupt!
  //musicPlayer.useInterrupt(VS1053_FILEPLAYER_TIMER0_INT); // timer int

  // If DREQ is on an interrupt pin (on uno, #2 or #3) we can do background
  // audio playing
  musicPlayer.useInterrupt(VS1053_FILEPLAYER_PIN_INT);  // DREQ int

  /*----------------------*/
  /*  I2C Initialization  */
  Wire.begin(5);                // join i2c bus with address #4
  Wire.onReceive(receiveEvent); // register event

  /*---------------------------*/
  /*  Test PBs Initialization  */
  pinMode(RESET_PB, INPUT);
  digitalWrite(RESET_PB, HIGH);
  pinMode(NEXT_PB, INPUT);
  digitalWrite(NEXT_PB, HIGH);
  pinMode(PLAY_PB, INPUT);
  digitalWrite(PLAY_PB, HIGH);
}

void loop() {
  // File is playing in the background
  //if (musicPlayer.stopped()) {
    //Serial.println("Done playing music");
    //while (1);
  //}
  if (Serial.available()) {
    char c = Serial.read();

    // if we get an 's' on the serial console, stop!
    if (c == 's') {
      musicPlayer.stopPlaying();
    }

    // if we get an 'p' on the serial console, pause/unpause!
    if (c == 'p') {
      if (! musicPlayer.paused()) {
        Serial.println("Paused");
        musicPlayer.pausePlaying(true);
      } else {
        Serial.println("Resumed");
        musicPlayer.pausePlaying(false);
      }
    }
  }

  if (digitalRead(RESET_PB) == LOW) {
    musicPlayer.stopPlaying();
    musicPlayer.softReset();
    currentTrackTest = 0;
    playing = false;
    delay(500);
  } else if (digitalRead(NEXT_PB) == LOW) {
    currentTrackTest ++;
    currentTrackTest %= 6;
    playTrack(currentTrackTest+1);
    delay(500);
  } else if (digitalRead(PLAY_PB) == LOW) {
    Serial.println(playing);
    if(playing){
      musicPlayer.stopPlaying();
      musicPlayer.softReset(); 
      playing = false;     
    }else{
      playing = true;
      playTrack(currentTrackTest+1);
    }    
    delay(500);
  }
  //delay(100);
}


//------------------------------
//------------------------------
// Rutina de interrupción de I2C
void receiveEvent(int howMany)
{
  if (x == 0) {
    x = Wire.read();
    if (x == 'v') {
      Serial.println("Setting volume");
    } else if (x == 't') {
      Serial.println("Setting track");
    } else if (x == 's') {
      Serial.println("Stopping...");
      musicPlayer.stopPlaying();
      musicPlayer.softReset();
      x = 0;
    } else {
      x = 0;
    }
  } else {
    if (x == 'v') {
      x = Wire.read();
      musicPlayer.setVolume(x, x);
      Serial.println((int)x);
    } else if (x == 't') {
      x = Wire.read();
      Serial.println(x);
      playTrack(x);
    }
    x = 0;
  }
}

void playTrack(int x) {
  musicPlayer.stopPlaying();
  switch (x) {
    case 1:
      if (!musicPlayer.startPlayingFile("track001.mp3")) Serial.println("Couldn't play track001.mp3");
      else Serial.println("Playing track001.mp3");
      break;
    case 2:
      if (!musicPlayer.startPlayingFile("track002.mp3")) Serial.println("Couldn't play track002.mp3");
      else Serial.println("Playing track002.mp3");
      break;
    case 3:
      if (!musicPlayer.startPlayingFile("track003.mp3")) Serial.println("Couldn't play track003.mp3");
      else Serial.println("Playing track003.mp3");
      break;
    case 4:
      if (!musicPlayer.startPlayingFile("track004.mp3")) Serial.println("Couldn't play track004.mp3");
      else Serial.println("Playing track004.mp3");
      break;
    case 5:
      if (!musicPlayer.startPlayingFile("track005.mp3")) Serial.println("Couldn't play track005.mp3");
      else Serial.println("Playing track005.mp3");
      break;
    case 6:
      if (!musicPlayer.startPlayingFile("track006.mp3")) Serial.println("Couldn't play track006.mp3");
      else Serial.println("Playing track006.mp3");
      break;
    default:
      x = 0;
      break;
  }
}

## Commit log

2014-08-04 Rev 1.2
    Rev 1.2
    [Cabinas.kicad_pcb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]
2014-08-04 BOM
    BOM
    [BOM.xlsx, Botonera.sch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]
2014-09-02 Codigo
    Codigo
    [BOM.xlsx]
2014-09-04 Mejora de codigo
2014-09-11 PCB Rev 1.3
    [BOM.xlsx, Cabinas.kicad_pcb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]
2014-09-15 Actualizacion de codigo
    [Tabla de rutinas.xlsx]
2014-09-23 Cambios
    *, #
    Optimizacion de memoria
    Aumento de tiempo de rutinas
2014-09-25 Apagado de protección
    Apagado de protección
    Eliminación de mensajes de depuración
2014-09-30 Cambios
    Los botones * y # ahora inician únicamente las canciones, no la rutina
    completa.
2014-09-30 Correcciones
    Correcciones de botonera
2014-09-30 Codigo de botonera
2014-10-14 Rev 1.4
    [Cabinas.kicad_pcb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]
2014-12-16 MP3 Breakout board
    MP3 Breakout board
    [MP3_Breakout.kicad_pcb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]
2015-01-19 Actualizacion de codigo
    actualizacion de codigo para mp3 estereo
2015-01-21 Rev 1.5
    Audio estereo
    [Cabinas.kicad_pcb, Cabinas.sch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]
2015-02-23 Firmware V3.0
    [Cabinas.kicad_pcb, Cabinas.sch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]
2015-03-19 REV 1.5
    Codigo V3.0
    [Cabinas.sch]
2015-04-06 Rev 3.0.2
    Se aumento el tiempo de rutina a 16 minutos
